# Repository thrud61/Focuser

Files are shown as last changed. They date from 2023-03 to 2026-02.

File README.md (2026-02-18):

# Focuser

A **Raspberry Pi Pico–based focuser** that emulates the **MoonLite focuser protocol**.

> ⚠️ **Status:** Work in progress in terms of release polish, but fully functional and currently in use on my own telescopes.

---

## Build Environment

- **IDE:** Arduino IDE  
- **Target:** Raspberry Pi Pico

---

## Overview

The MoonLite focuser uses a simple **ASCII-based serial protocol**, commonly referred to as the *MoonLite protocol*.  
Commands are typically sent over a **virtual COM port (RS232)** at **9600 baud**.

### Protocol Notes

- All commands **start with `:`** and **end with `#`**
- Numeric values are usually **hexadecimal**
- Hex values are typically **fixed-width** (e.g. `0000`–`FFFF`)

---

## Supported MoonLite Commands

### Movement & Status

| Command | Description |
|---|---|
| `:FG#` | Go to target position (moves motor to value set by `:SNxxxx#`) |
| `:FQ#` | Stop movement |
| `:GI#` | Get moving status (`01` = moving, `00` = stopped) |
| `:GN#` | Get target position (returns 4-character hex) |
| `:GP#` | Get current position (returns 4-character hex) |

### Position Control

| Command | Description |
|---|---|
| `:SNxxxx#` | Set new target position (4-character hex) |
| `:SPxxxx#` | Set current position (sync/set position to `xxxx`) |

### Temperature & Compensation

| Command | Description |
|---|---|
| `:CG#` | Start temperature conversion |
| `:GT#` | Get current temperature |
| `:GC#` | Get temperature coefficient |
| `:SCxx#` | Set new temperature coefficient |
| `:PLUS#` | Enable temperature compensation |

### Stepper Configuration

| Command | Description |
|---|---|
| `:GD#` | Get stepping delay (returns 2-character hex) |
| `:SDxx#` | Set stepping delay (`02`, `04`, `08`, `10`, `20`) |
| `:GH#` | Get half-step mode (`FF` = half, `00` = full) |
| `:SF#` | Set full-step mode |
| `:SH#` | Set half-step mode |

### Firmware Information

| Command | Description |
|---|---|
| `:GV#` | Get firmware version |

---

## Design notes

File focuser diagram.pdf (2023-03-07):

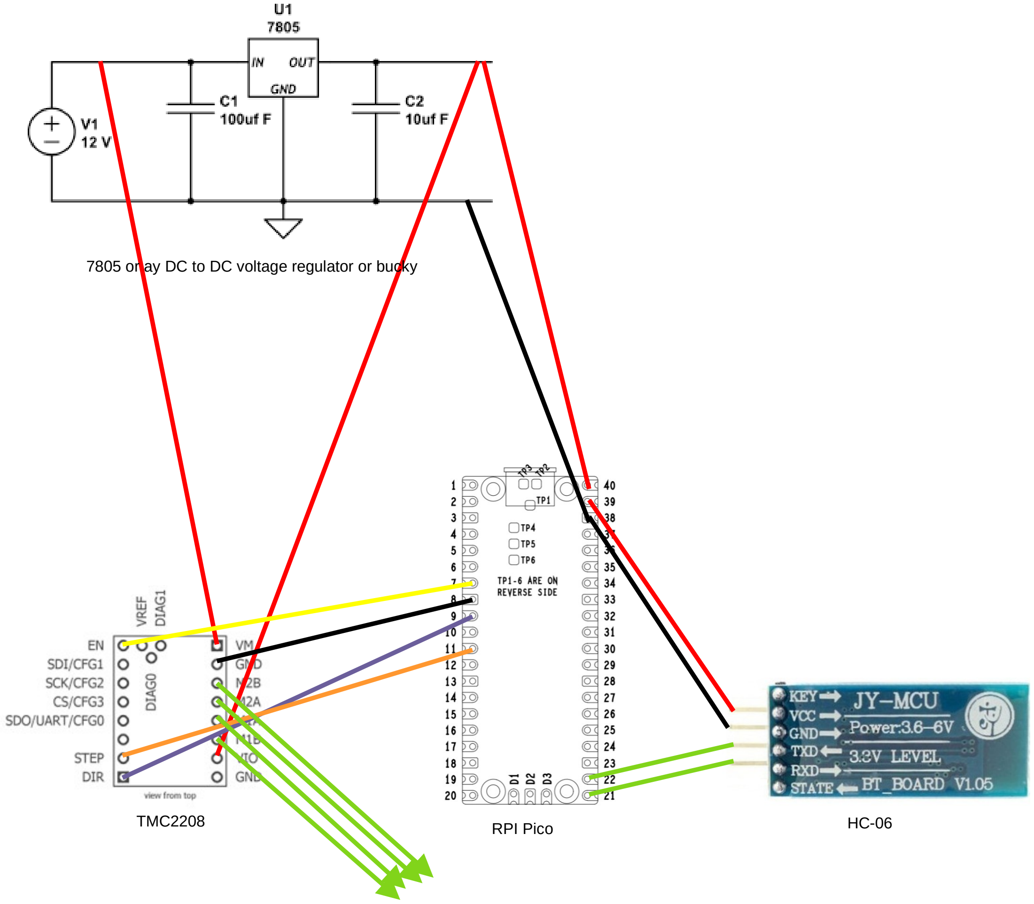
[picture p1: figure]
TMC2208; RPI Pico

To

# Stepper Motor

7805 or ay DC to DC voltage regulator or bucky

# Auto focuser based on Rpi Pico

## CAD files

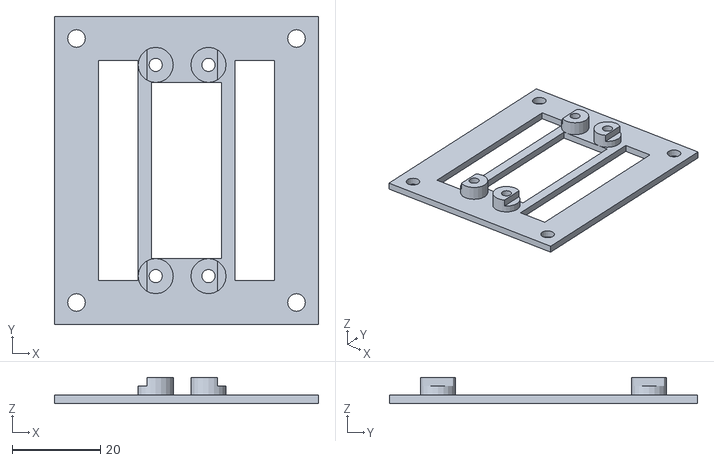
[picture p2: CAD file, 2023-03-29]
Focuser 3D models/rpi to pico mounting adaptor.stl
60.0 x 70.0 x 6.00

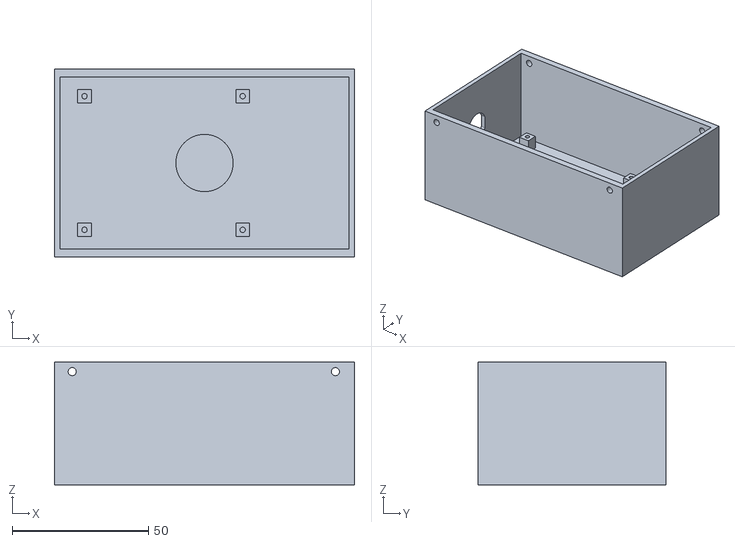
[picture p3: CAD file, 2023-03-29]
Focuser 3D models/focuser electronics box.stl
110.0 x 69.0 x 45.0

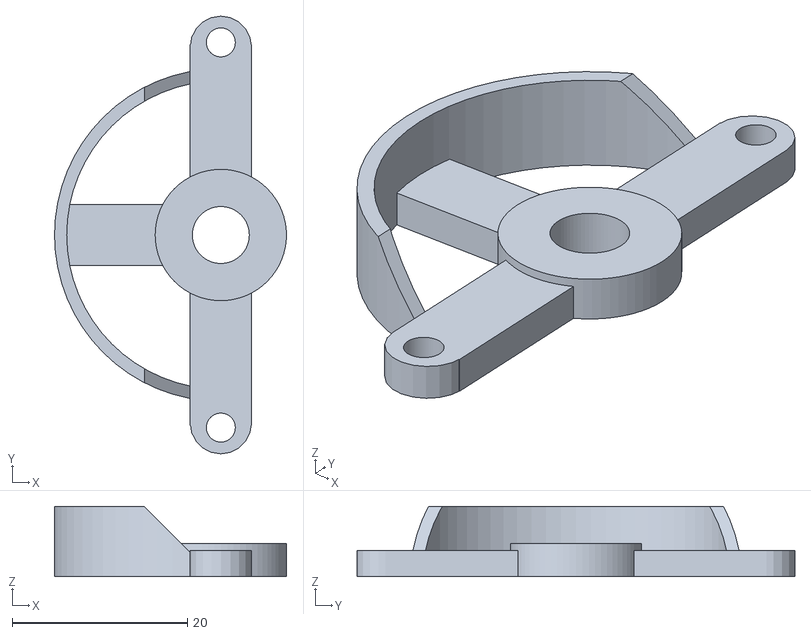
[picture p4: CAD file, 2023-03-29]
Focuser 3D models/stepper retainer-A.stl
26.5 x 50.0 x 8.00

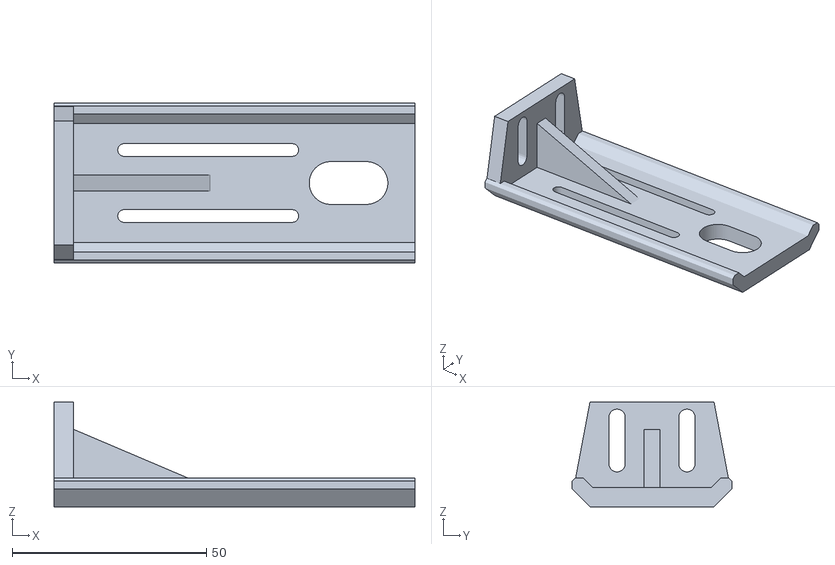
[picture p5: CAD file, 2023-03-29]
Focuser 3D models/focuser bracket.stl
93.0 x 41.2 x 27.0

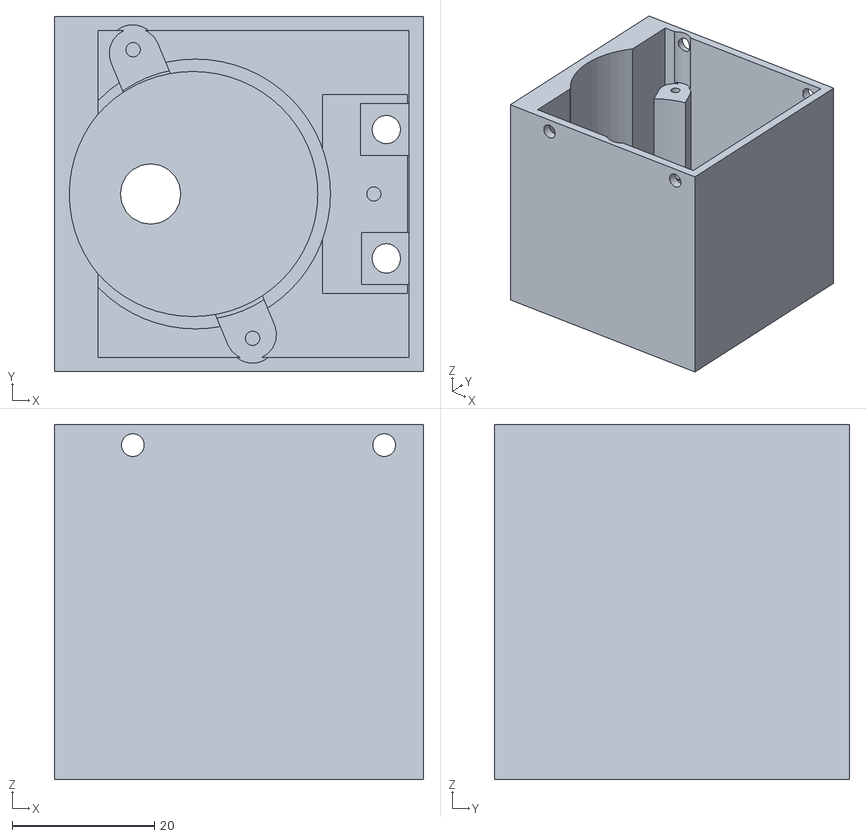
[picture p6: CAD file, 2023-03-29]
Focuser 3D models/focuser stepper box.stl
52.0 x 50.0 x 50.0

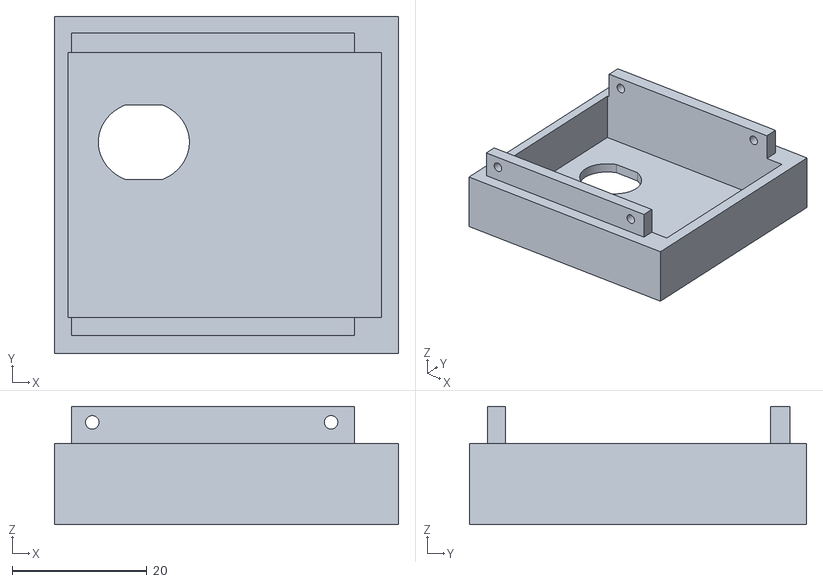
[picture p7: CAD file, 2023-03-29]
Focuser 3D models/focuser stepper box lid.stl
51.0 x 50.0 x 17.5

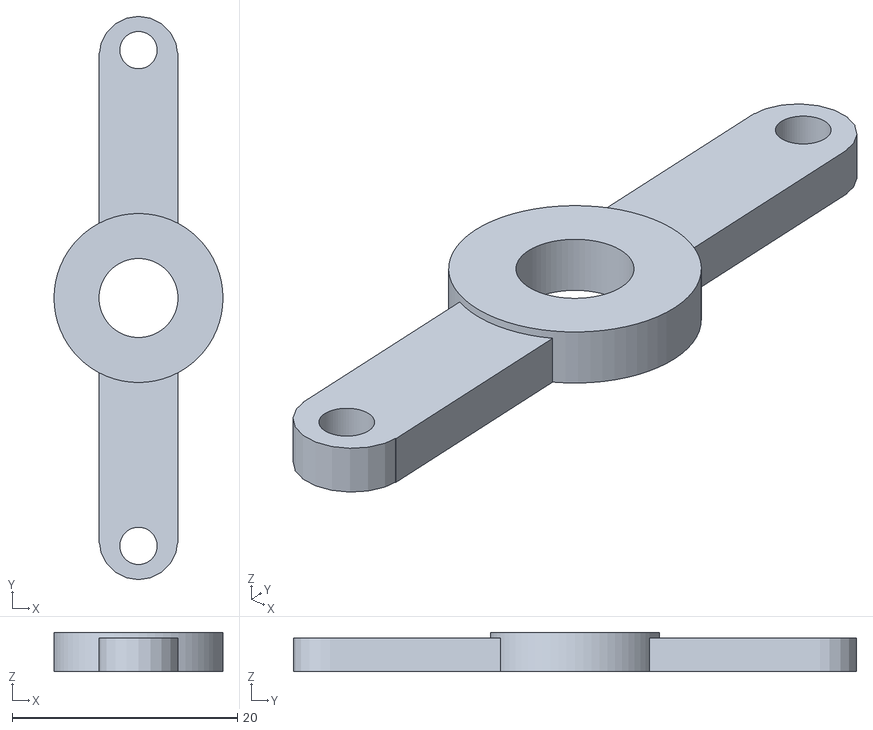
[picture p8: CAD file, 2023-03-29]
Focuser 3D models/stepper retainer B.stl
15.0 x 50.0 x 3.50

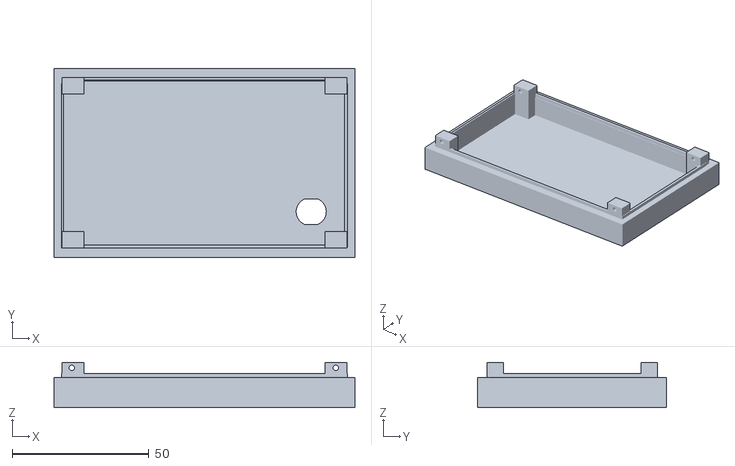
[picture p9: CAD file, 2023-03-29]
Focuser 3D models/focuser electronics box lid.stl
110.0 x 69.0 x 16.5

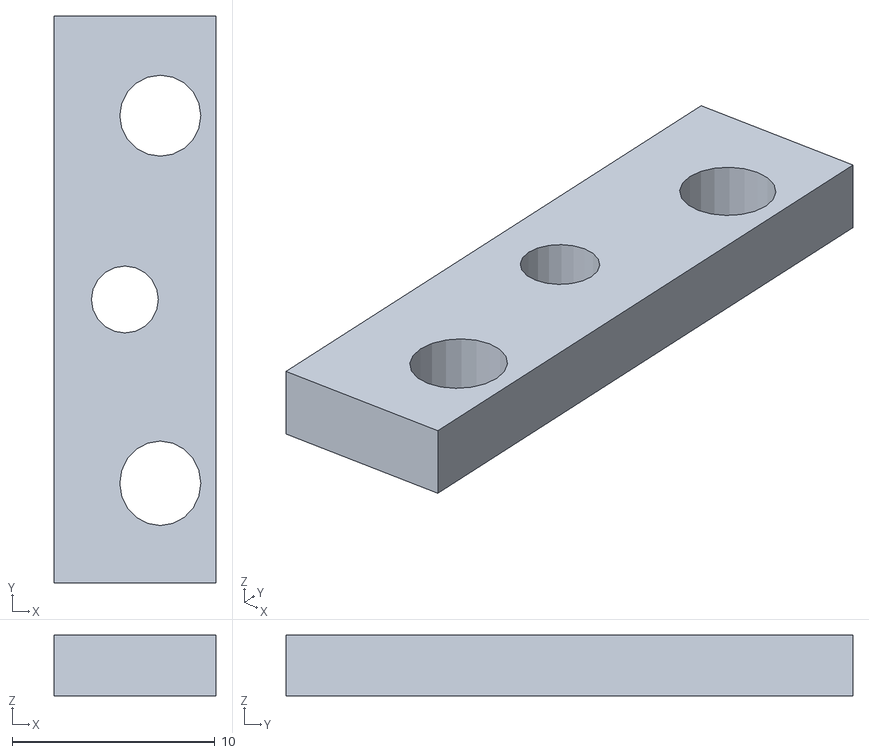
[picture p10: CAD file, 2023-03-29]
Focuser 3D models/square nut retainer.stl
8.00 x 28.0 x 3.00

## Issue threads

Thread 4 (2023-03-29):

Add  3D models

thrud61, 2023-03-29:
Need to add the 3D stl files to allow the various mounting brackets and boxes for housing the electronics and stepper motors to be printed.

Closed 2023-03-29.

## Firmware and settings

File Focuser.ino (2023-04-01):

// Focuser controller for telescopes, emulates the moonlite focuser protocol
// allowing use of the ascom drivers for the moonlite, saving having to write COM+ drivers.
// Can be used with the TMC22xx or with the UL2003 if its needed (github.com/thrud61/ul2003)
//
// Author James Wilson
// 1st November 2021
//

#include <FreeRTOS.h>
#include <queue.h>

#include "pico/stdlib.h"
#include "hardware/uart.h"
#include "hardware/irq.h"


#include <cstring>
#include <string>

#include "tmc22xx.h"

#define UART_ID uart0
#define BAUD_RATE 9600
#define DATA_BITS 8
#define STOP_BITS 1
#define PARITY    UART_PARITY_NONE

// We are using pins 16 and 17 for UART0
#define UART_TX_PIN 16
#define UART_RX_PIN 17

// need a queue for each core/thread
QueueHandle_t xISRQueue = NULL;
QueueHandle_t xMoveQueue = NULL;

// create the motor object, in this case its using the tmc2208 and the 35PM48L01-05B stepper motor
// we can also use the less powerful 28BYJ-48 converted to bipolar https://ardufocus.com/howto/28byj-48-bipolar-hw-mod/
Motor motor;

// led state variable (sort of)
static int led = 1;

// function that implements the moonlite focuser protocol based on this doc https://indilib.org/media/kunena/attachments/1/HighResSteppermotor107.pdf
// allows me to use the standard ascom driver for the moonlite focuser https://focuser.com/media/Downloads/MoonLite_Software/Ascom/MoonLite%20DRO%20Setup.zip
// also the Moonlite Focuser Control from here https://focuser.com/media/Downloads/MoonLite_Software/NonAscom/MoonliteSingleFocuser_v1.4.zip
std::string do_moonlite(std::string &, Motor &);

// Core 0 loop process waiting for messages from the UART0 ISR
// calls the moonlite protocol handler and sends any out put to the UART tx
void MoonliteProcess(void)
{
  char buffer[20];
  static int led = 1;

  // lets flash the led at 1/10th of the actual call rate
  led++;
  gpio_put(PICO_DEFAULT_LED_PIN, (led / 10) & 1);

  // wait for a message from the uart isr
  if (xQueueReceive(xISRQueue, buffer, (TickType_t) 10) == pdTRUE)
  {

      // do protocol stuff, we only know moonlite
      std::string out = do_moonlite(buffer, motor);

      // do we have a response, then send it on
      if (out.size() > 0)
      {
        // Can we send it back?
        if (uart_is_writable(UART_ID))
        {
          uart_puts(UART_ID, out.c_str());
        }
      }
  }
}

// UART0 RX interrupt handler, don't need a TX isr
void on_uart_rx()
{
  // we are going to maintain these variable across all interrupts
  static int state = 1;
  static int b_pos = 0;
  static char buffer[20]; // does not need to be big, we only really need 9 bytes

  // really should be an error if there is nothing to read
  // but its a pico so we will just carry on
  while (uart_is_readable(UART_ID))
  {
    // fetch a single char from the uart
    uint8_t ch = uart_getc(UART_ID);
    BaseType_t xTaskWoken; // needed for calling the queue send, we don't care

    // pick out the input command :ccxxxx#
    // its a state machine only 2 states but it counts
    switch (state)
    {
      case 1: // looking for :, its our stx
        {
          // not : then get next char
          if (ch != ':')
            continue;

          // initialise the command buffer, move to next state
          b_pos = 0;
          memset(buffer, 0, 20);
          state = 3;
        }
        break;

      case 2: // looking for #, its our etx, or [setting=x] when we implement it
        {
          // we will keep everything thats not etx
          if (ch != '#')
          {
            // if we get stx then reset command buffer
            if (ch == ':')
            {
              b_pos = 0;
              memset(buffer, 0, 20);
              state = 2; // we are staying in this state
              continue;
            }
            buffer[b_pos++] = ch;
          }
          else
          {
            // got a complete command send message to the moonlite process core 0
            if ( xQueueSendFromISR( xISRQueue, ( void * ) buffer, &xTaskWoken) != pdPASS )
            {
              // send error to USB port, this is an example Serial.printf can be used for debugging
              //              Serial.printf ("failed message %s\n", buffer);
            }
            state = 1;
            b_pos = 0;
          }
          // something went wrong
          if (b_pos > 16)
            state = 1;
        }
        break;

    }
  }
}

// standard arduino run once for core 0
void setup()
{
  //  Serial.begin(115200);

  // couple of queues to communicate between cores and isr
  xISRQueue = xQueueCreate( 10, 10);
  xMoveQueue = xQueueCreate( 10, sizeof(int));

  gpio_init(PICO_DEFAULT_LED_PIN);
  gpio_set_dir(PICO_DEFAULT_LED_PIN, GPIO_OUT);
  gpio_put(PICO_DEFAULT_LED_PIN, 1);

  // Set up our UART with a basic baud rate.
  uart_init(UART_ID, 9600);

  // Set the TX and RX pins by using the function select on the GPIO
  // Set datasheet for more information on function select
  gpio_set_function(UART_TX_PIN, GPIO_FUNC_UART);
  gpio_set_function(UART_RX_PIN, GPIO_FUNC_UART);

  // Actually, we may want a different speed
  // The call will return the actual baud rate selected, which will be as close as
  // possible to that requested, which we will ignore. But we got it right first time so....
  //  int __unused actual = uart_set_baudrate(UART_ID, BAUD_RATE);

  // Set UART flow control CTS/RTS, we don't want these, so turn them off
  uart_set_hw_flow(UART_ID, false, false);

  // Set our data format
  uart_set_format(UART_ID, DATA_BITS, STOP_BITS, PARITY);

  // Turn on FIFO's - we want to do this character by character but we don't want to miss a char
  uart_set_fifo_enabled(UART_ID, true);

  // Set up a RX interrupt
  // We need to set up the handler first
  // Select correct interrupt for the UART we are using
  int UART_IRQ = UART_ID == uart0 ? UART0_IRQ : UART1_IRQ;

  // And set up and enable the interrupt handlers
  irq_set_exclusive_handler(UART_IRQ, on_uart_rx);
  irq_set_enabled(UART_IRQ, true);

  // Now enable the UART to send interrupts - RX only
  uart_set_irq_enables(UART_ID, true, false);

  // OK, all set up.
  // Lets run a loop and wait for RX interrupts
  // everything happens in the irq handler
}

// core 0 process
void loop()
{
  MoonliteProcess();
}

// core 1 used for moving the stepper asynchronously
void loop1()
{
  int buffer;

  // used to do async move, if we get a message we will try to move, don't care it we don't actually move
  if (xQueueReceive(xMoveQueue, &buffer, (TickType_t) 10) == pdTRUE)
  {
    if (motor.is_moving())
      motor.move();
  }
}

// Moonlite focuser protocol emulation
// worked out from https://indilib.org/media/kunena/attachments/1/HighResSteppermotor107.pdf
// mine ignores half steps cmd though it is implemented in the code, ignores temp calibration and other non-essential commands
std::string do_moonlite(char *buffer, Motor & motor)
{
  char out[10] = "";
  int v;
  unsigned int s, e;

  //
  // lets ignore the temp compensation stuff C + -
  // we can add later if its needed and we can work out
  // what it actually means

  // check the first char of the command
  // G = get
  // S = Set
  // F = Do something physical
  switch (buffer[0])
  {
    case 'G': // GET
      switch (buffer[1])
      {
        case 'B':
        case 'C':
          strcpy(out, "00#");
          break;
        case 'V':
          strcpy(out, "10#");
          break;
        case 'T':
          sprintf(out, "%04X#", int(analogReadTemp() * 2));
          break;
        case 'I':
          sprintf(out, "%02X#", motor.moving);
          break;
        case 'P':
          sprintf(out, "%04X#", motor.position / motor.settings["fullsteps"]);
          break;
        case 'N':
          sprintf(out, "%04X#", motor.target / motor.settings["fullsteps"]);
          break;
        case 'H':
          sprintf(out, "%s", motor.settings["fullsteps"] == 2 ? "FF#" : "FF#");
          break;
        case 'D':
          sprintf(out, "%02d#", motor.settings["D"]);
          break;
      }
      break;
    case 'S': // SET
      switch (buffer[1])
      {
        case 'F':
          /*
              // fix partial step on odd position
              if ((motor.position & 1) == 1)
                  motor.target = (motor.position/2)*2;

              if (motor.target != motor.position)
              {
                  printf("fix %d %d\n",motor.target, motor.position);
                  motor.moving = true;
                  motor.nudge();
              }
          */
          motor.settings["fullsteps"] = 1;
          break;
        case 'H': // not supporting half steps currently
          // motor.settings["fullsteps"]=1;
          break;
        case 'N':
          sscanf(buffer, "SN%X", &v);

          if (!motor.moving)
            motor.target = v * motor.settings["fullsteps"];
            
          break;
        case 'P':
          sscanf(buffer, "SP%X", &v);

          if (!motor.moving)
            motor.position = v * motor.settings["fullsteps"];
          break;
        case 'D':
          sscanf(buffer, "SD%d", &v);
          if (!motor.moving)
          {
            motor.settings["speed"] = (motor.settings["max_speed"] * 2) / v; // gives us 40 to 4 RPM on the shaft
            motor.settings["D"] = v;
          }
          break;

      }
      break;
    case 'F': // Do stuff
      switch (buffer[1])
      {
        case 'G':
          if (!motor.moving)
          {
            motor.moving = true;
            if ( xQueueSend( xMoveQueue, ( void * ) 1, (TickType_t) 10) != pdPASS )
            {
              //Serial.printf ("failed message %s\n", buffer);
            }
          }
          break;
        case 'Q':
          motor.halt();
          break;
      }
      break;
    default:
      break;
  }

  return std::string(out);
}

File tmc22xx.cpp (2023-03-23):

// Class to drive the TMC22xx stepper driver chips, with very little tweaking
// can also be used with most stepper drivers, minor changes needed for the
// A4998 driver (or none if direction of travel is not important)
// 
// bare metal pico implementation
//
// Author James Wilson
// 5th October 2021
//
#include "tmc22xx.h"

//#define DEBUG 1

Motor::Motor()
{
  settings["fullsteps"] = 1;
  settings["steps"] = 1012;  // nema motor 1.8 deg
  settings["accel"] = true;
  settings["speed"] = 40;   // rpm
  settings["max_steps"] = settings["steps"] * 100; // we will wrap around at this point
  settings["position"] = 1;
  settings["limit"] = 3600;
  settings["invert"] = 0;
  settings["max_speed"] = 4;

  settings["D"] = 2;

  moving = false;

  // set them to output
  for (int pin : motor_pins)
  {
    gpio_init(pin);
    gpio_set_dir(pin, GPIO_OUT);
  }

  // gpio 23 for end stop
  //    pinMode(23, INPUT);
  //    pullUpDnControl (23, PUD_UP);

  // set non-energised state
  halt();
}

bool Motor::is_moving()
{
  return moving;
}

void Motor::halt()
{
  if (debug)
    printf("Halt\n");
  moving = false;
  sleep_ms(100); // wait 100ms to give the move time to notice if its async
  for (int pin : motor_pins)
  {
    gpio_put(pin, 1);
  }
}

// take a single step
void Motor::step(int pos)
{
  // don't go past the limit
  if (position >= settings["limit"])
    return;

  if (debug == 2)
    printf("Step %d\n", pos);

  // check the end stop
  //    if (!digitalRead(23))
  //    {
  //        if (debug)
  //            printf("End Stop\n");
  //
  //        halt();
  //    }

  step_state = !step_state;
  gpio_put(pDir, direction < 0 ? 1 : 0);
  gpio_put(pStep, step_state);
}

void Motor::async_move(int new_pos)
{
  moving = true;
  target = new_pos;
  return async_move();
}
void Motor::async_move(void)
{
  // not like this on bare metal
  //    async_m = std::async(std::launch::async, [&](){move();});
}

void Motor::wait(void)
{
  //     async_m.wait();
}

int Motor::move(int new_pos)
{
  target = new_pos;
  return move();
}

// move 1 step, used when switching from half to full steps
// to sync to full step position
void Motor::nudge(void)
{
  int delay;

  if (debug)
    printf("Nudge\n");

  gpio_put(pEnable, 0);

  // do some stuff with the motor
  delay = (1000000 / ((settings["speed"] * (settings["steps"])) / 60));

  if (position > target)
    direction = -1;
  else
    direction = 1;

  // ensure we stay within the limits of the scope
  if ((position < settings["limit"]) && (position + direction >= 0))
  {
    step(position);
    sleep_us(delay);

    position += direction;
    position = position % settings["max_steps"];
  }

  halt();
}

// move to a specific position
int Motor::move(void)
{
  int slow = 0;
//  int delay;

  if (debug)
    printf("Move %d %d\n", position, target);

  gpio_put(pEnable, 0);

  // do some stuff with the motor
  delay = (1000000 / ((settings["speed"] * (settings["steps"] / settings["fullsteps"])) / 60)) / 2;

  if (debug)
    printf("delay %d, target, position\n", delay, target, position);

  if (settings["accel"])
    slow = 20000;

  if (position > target)
    direction = -settings["fullsteps"];
  else
    direction = settings["fullsteps"];

  // someone can stop this with moving set to false
  while ((target != position) && moving && (position + direction < settings["limit"]) && (position + direction >= 0))
  {
    if (moving)
    {
      position += direction;
      position = position % settings["max_steps"];

      if (settings["accel"])
      {
        if (abs(target - position) < 200)
        {
          slow += 100 * settings["fullsteps"];
        }
        else if (slow)
        {
          slow -= 100;
          if (slow < 0)
            slow = 0;
        }
      }
      step(position);
      sleep_us(delay);
      step(position);
      sleep_us(delay);
    }
  }
  halt();

  return position;
}

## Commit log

2023-03-23 Update tmc22xx.h
    Remove unused header for raspberry pi implementation
2023-03-29 3D models added
    £D models to allow printing of all the plastic boxes and brackets
    [focuser bracket.stl, focuser electronics box lid.stl, focuser electronics box.stl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]
